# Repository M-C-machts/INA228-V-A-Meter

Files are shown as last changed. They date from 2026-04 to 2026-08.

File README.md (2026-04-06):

# INA228-V-A-Meter

A KiCad 9 hardware project for a compact voltage and current meter/logger using:
- **TI INA228** - high-accuracy current/voltage/power monitor
- **Seeed XIAO ESP32-C3** - MCU module

The board is **powered from a LiFePO₄ battery** and charged via the **XIAO's USB-C port**.

> **Status:** Work in progress. Some changes may occur.

---

## Features
- Simultaneous **bus voltage** and **current** measurement via INA228
- ESP32-C3 firmware
- LiFePO₄ battery powered - portable
- 1.3" OLED display

---

## Hardware Overview
### Main Components
- **INA228**: measures shunt and bus voltage; performs current/power calculations internally
- **XIAO ESP32-C3**: reads INA228 over **I²C** and outputs/logs data
- LiFePO₄ charge/discharge power management is handled via a daughter board: [XIAO-LiFePO4-Power-Module](https://github.com/M-C-machts/XIAO-LiFePO4-Power-Module)
- Gerber files for PCB fabrication are included
- Case files for 3D printing are included

### Power
- The board is powered by a **LiFePO₄ cell**.
- Charging is handled **through the XIAO USB-C port** via the daughter board. The XIAO's onboard charger/power path is not used.
- To use a LiPo battery instead, omit the XIAO-LiFePO4-Power-Module and connect a *protected* LiPo battery directly to the XIAO battery solder pads.

---

## Firmware
- Reads INA228 registers via I²C
- Calculates and displays:
  - Voltage (V)
  - Current (A)
  - Power (W) *(optional)*
- Outputs data over USB serial and 1.3" OLED display

## Calibration / Accuracy Notes
INA228 measurement accuracy depends heavily on:
- Shunt resistor value, tolerance, and temperature coefficient
- Correct INA228 configuration (averaging, conversion times, calibration register)

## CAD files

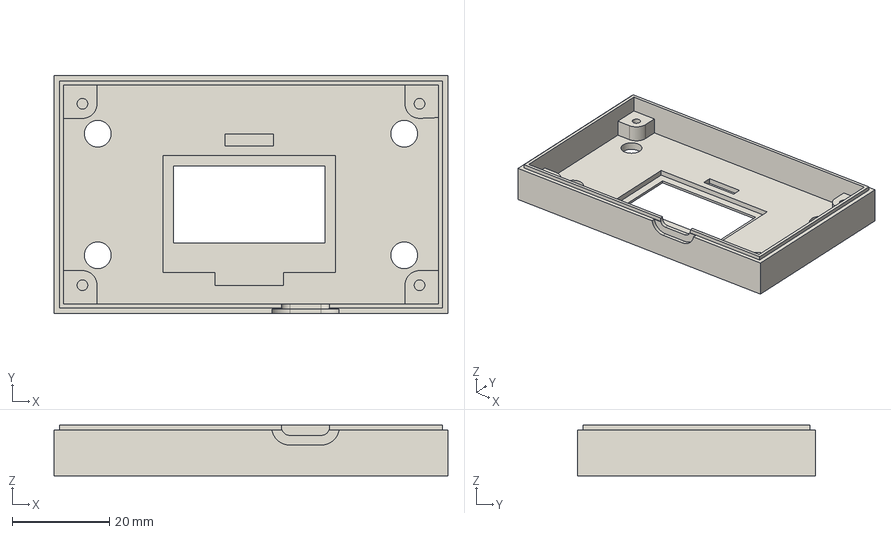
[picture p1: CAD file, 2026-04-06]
hardware/case/case-top_INA228-V-A-Meter.step
81.0 x 49.0 x 10.4 mm

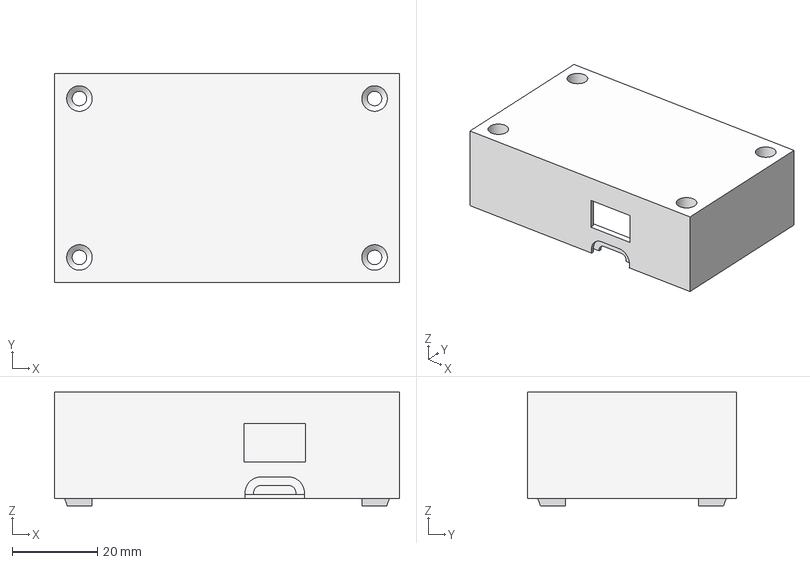
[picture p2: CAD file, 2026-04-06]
hardware/case/case-bottom_INA228-V-A-Meter.step
81.0 x 49.0 x 26.7 mm

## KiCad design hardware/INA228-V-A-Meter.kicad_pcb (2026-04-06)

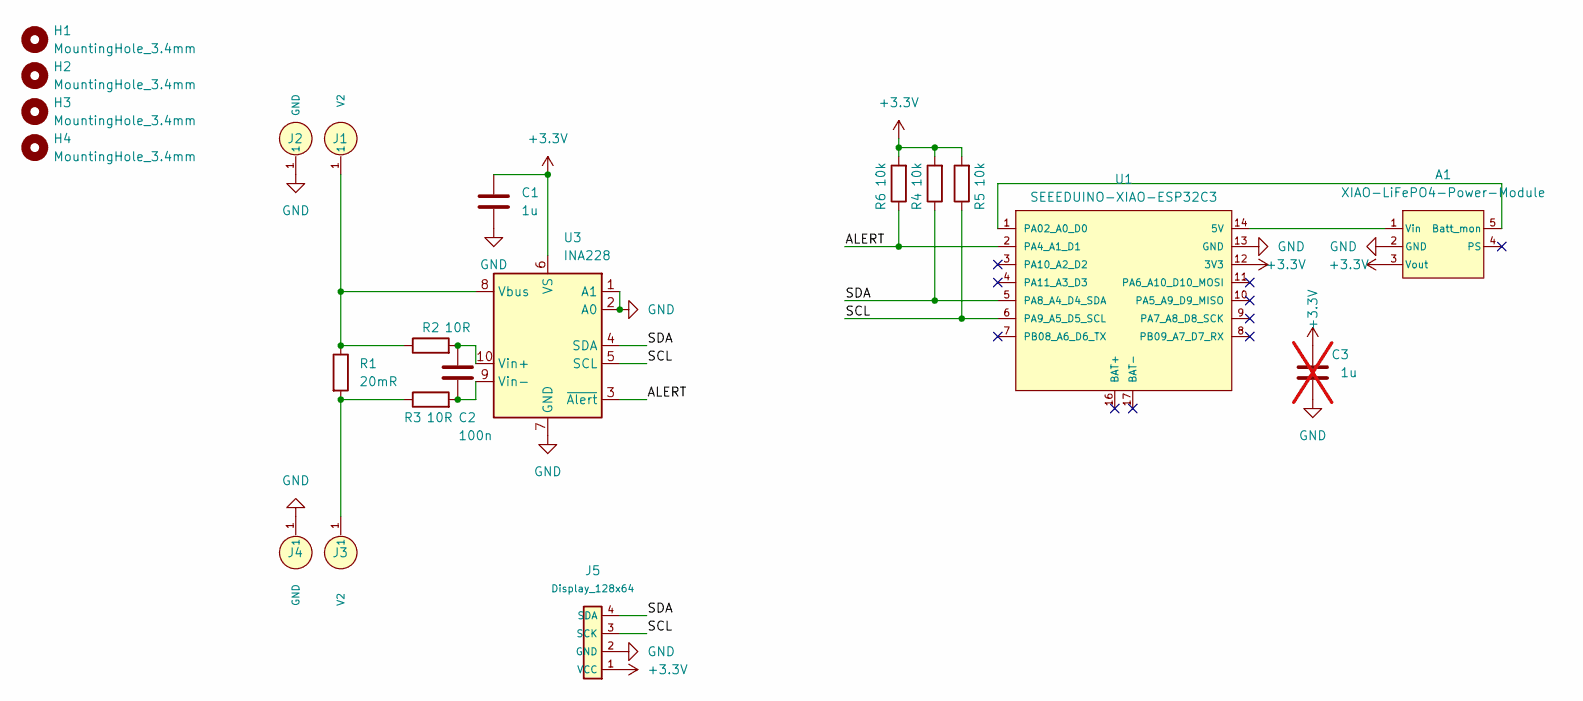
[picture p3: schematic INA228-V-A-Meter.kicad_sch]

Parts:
A1: XIAO-LiFePO4-Power-Module
C1: 1u; C_0603_1608Metric
C2: 100n; C_0603_1608Metric
C3: 1u; C_0805_2012Metric; not fitted
H1, H2, H3, H4: MountingHole_3.4mm; MountingHole_3.2mm_M3
J1, J2, J3, J4: Banana-Socket; banana-socket; Mouser Part Number 534-575-4
J5: Display-OLED-1.3-Module
R1: 20mR; R_2512_6332Metric
R2, R3: 10R; R_0805_2012Metric
R4, R5, R6: 10k; R_0805_2012Metric
U1: SEEEDUINO-XIAO-ESP32C3
U3: INA228; VSSOP-10_3x3mm_P0.5mm

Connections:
+3.3V: A1.3 (Vout), C1.1, C3.1, J5.1 (VCC), R4.2, R5.2, R6.2, U1.12 (3V3), U3.6 (VS)
/ALERT: R6.1, U1.2 (PA4_A1_D1), U3.3 (~Alert)
/SCL: J5.3 (SCK), R5.1, U1.6 (PA9_A5_D5_SCL), U3.5 (SCL)
/SDA: J5.4 (SDA), R4.1, U1.5 (PA8_A4_D4_SDA), U3.4 (SDA)
GND: A1.2 (GND), C1.2, C3.2, J2.1, J4.1, J5.2 (GND), U1.13 (GND), U3.1 (A1), U3.2 (A0), U3.7 (GND)
unnamed: A1.5 (Batt_mon), U1.1 (PA02_A0_D0)
unnamed: A1.1 (Vin), U1.14 (5V)
unnamed: J3.1, R1.2, R3.1
unnamed: J1.1, R1.1, R2.1, U3.8 (Vbus)
unnamed: C2.1, R2.2, U3.10 (Vin+)
unnamed: C2.2, R3.2, U3.9 (Vin-)

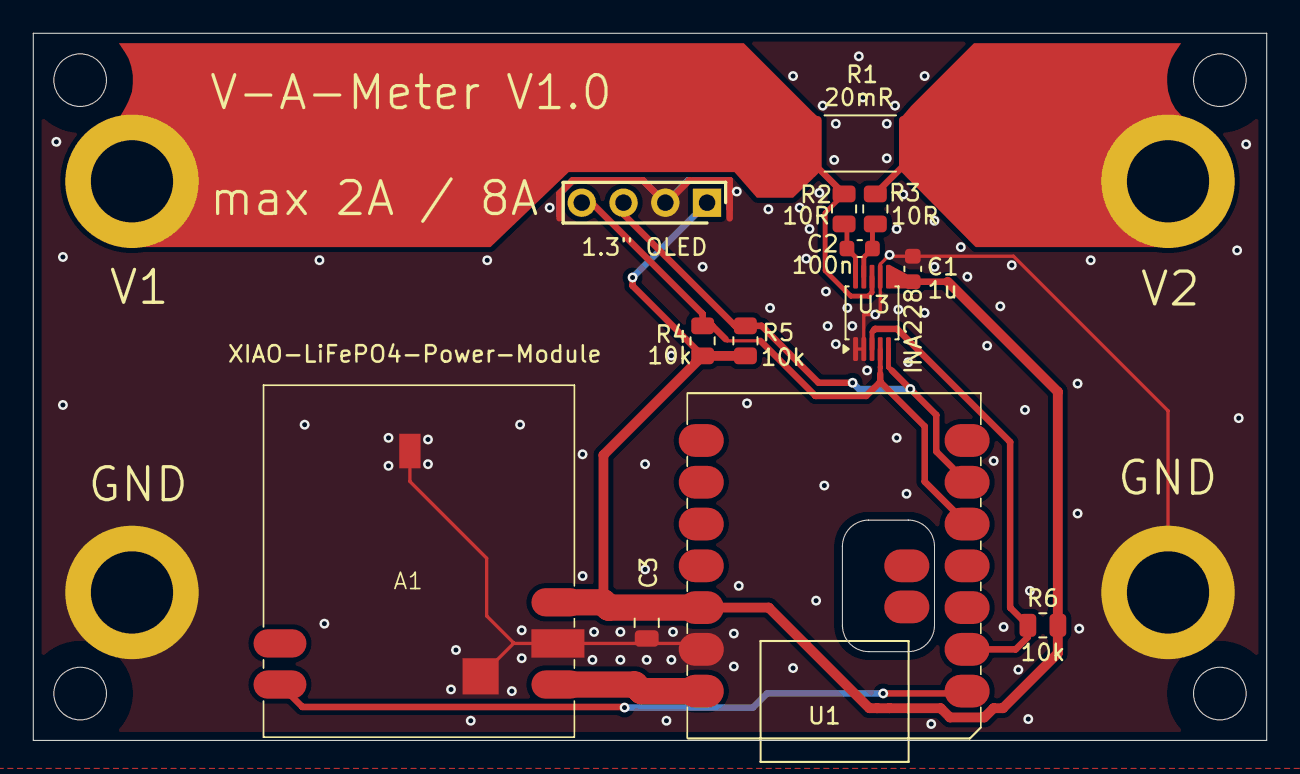
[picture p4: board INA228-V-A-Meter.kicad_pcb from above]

Board: 2 copper layers, 75.0 x 43.0 mm, 21 parts (0 on the bottom side), 11 nets.

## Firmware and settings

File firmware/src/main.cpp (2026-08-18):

#include <Arduino.h>
#include <Wire.h>

#include <Adafruit_GFX.h>
#include <Adafruit_SH110X.h>

#include <Adafruit_INA228.h>

// --- I2C addresses (typical) ---
static constexpr uint8_t OLED_ADDR = 0x3C;     // sometimes 0x3D
static constexpr uint8_t INA_ADDR    = 0x40;

// --- SH1106 128x64 over I2C ---
Adafruit_SH1106G oled(128, 64, &Wire, -1);

// --- INA228 ---
Adafruit_INA228 ina228;

// Pick a display refresh that is <= INA228 "new-data" cadence
static constexpr uint32_t DISPLAY_UPDATE_MS = 500;

static bool oled_begin_try(uint8_t addr) {
    return oled.begin(addr, true); // addr, reset=true
}

void setup() {
    Serial.begin(115200);
    delay(100);

    Wire.begin();
    // Optional: faster I2C transfers (doesn't change measurement accuracy)
    // Wire.setClock(400000);

    // OLED init (try 0x3C then 0x3D)
    if (!(oled_begin_try(0x3C) || oled_begin_try(0x3D))) {
        Serial.println("SH1106 init failed");
        while (true) delay(1000);
    }

    oled.clearDisplay();
    oled.setTextColor(SH110X_WHITE);
    oled.setTextSize(1);
    oled.setCursor(0, 0);
    oled.println("OLED OK");
    oled.display();

    // INA228 init
    if (!ina228.begin(INA_ADDR, &Wire)) {
        Serial.println("INA228 init failed");
        oled.clearDisplay();
        oled.setCursor(0, 0);
        oled.println("INA228 init failed");
        oled.display();
        while (true) delay(1000);
    }

    // IMPORTANT: set the *real* shunt value you are using.
    ina228.setShunt(0.020f, 2.0f);

    // "Accurate-looking": internal averaging + longer conversion times = less noise, slower updates
    ina228.setAveragingCount(INA228_COUNT_256);
    ina228.setVoltageConversionTime(INA228_TIME_1052_us);
    ina228.setCurrentConversionTime(INA228_TIME_1052_us);
    ina228.setTemperatureConversionTime(INA2XX_TIME_150_us);
}

void loop() {
    static uint32_t last = 0;
    uint32_t now = millis();
    if (now - last < DISPLAY_UPDATE_MS)
        return;
    last = now;

    // Read values
    const float i_mA = ina228.getCurrent_mA();
    const float v_bus = ina228.getBusVoltage_V();
    const float t_die = ina228.readDieTemp();

    // OLED output
    oled.clearDisplay();
    oled.setCursor(0, 0);

    oled.setTextSize(1);
    oled.print("INA228  Tdie ");
    oled.print(t_die, 2);
    oled.print(" C\n\n");

    oled.setTextSize(2);
    oled.print("I ");
    oled.print(i_mA, 1);
    oled.print("mA\n");

    oled.setTextSize(1);
    oled.print("\n");
    oled.setTextSize(2);

    oled.print("U ");
    oled.print(v_bus, 4);
    oled.print(" V\n");

    oled.display();

    // Optional serial debug
    Serial.printf("I=%.3f mA  Vbus=%.4f V  Tdie=%.2f C\n", i_mA, v_bus, t_die);
}

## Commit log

2026-02-19 Add V-A-Meter Project, needs testing
    [V-A-Meter.kicad_pcb, V-A-Meter.kicad_sch]
2026-04-06 Rework PCB
    [INA228-V-A-Meter-V2.kicad_pcb, INA228-V-A-Meter.kicad_sch]
2026-04-06 Rework PCB, Add fabrication and case
    [INA228-V-A-Meter.kicad_pcb, case-bottom_INA228-V-A-Meter.step, case-top_INA228-V-A-Meter.step]
